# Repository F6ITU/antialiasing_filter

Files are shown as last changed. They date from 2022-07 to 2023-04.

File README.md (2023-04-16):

Cerberus, a triple path antialiasing filter for RF Software defined radio

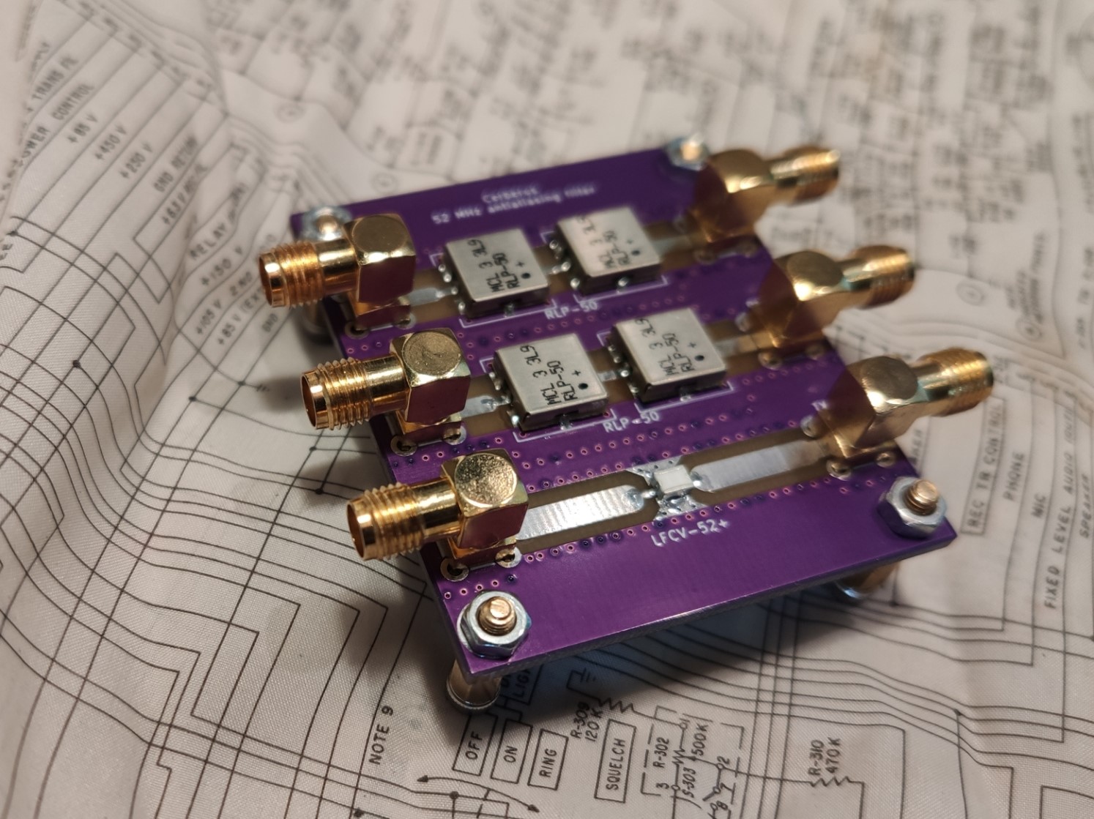
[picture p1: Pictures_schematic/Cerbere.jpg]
Cerberus, the 2 RX, 1 TX 52 MHz low path antialiasing filter


Cerberus is a simple series of three 52 MHz low pass filters designed to eliminate the second Nyquist zone of any "bare foot" 
120 MSPS baseband software defined HF transceiver. One filter is used in the Transmission path, two distinct filters could be used for 
two different RX path.

A single LTCC filter is dedicated to the TX output able to withstand up to 8W CW. It's rejection level is around 50 dB in the stopband area.
This filter should be  completed with a post-amplifier low pass filter. 

Two RX path (for 2 separated ADCs) are based on a pair of cascaded RLP-50+ low pass filters, thus offering a rejection of 50 dB each

Each of these path could be used with or without an RF preselector (bandpass filter or low pass filter) 

This antialiasing frontend should be inserted just after the baseband board (Red Pitaya 14 or 16 bits, IQsdr etc)and before 
the SDR frontend (in other words, a simple bandpass filter, a more complex "Alexiares like" preselector, or a combination of 
Alexiares or entry level filters and a set of high power frontend (Zolotaref lpf, Aries ATU, Munin amplifier etc

As usual, this board is under the CERN Open Hardware licence

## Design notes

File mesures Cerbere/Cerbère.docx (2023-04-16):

Cerbère (Κέρϐερος) est le chien tricéphale, gardien des enfers. Ce gardien-là préserve le SDR des démons provenant des secondes, troisièmes et quatrièmes zones de nyquist. C’est un triple filtre passe-bas destiné à tous les transceivers bande de base couvrant de 0,1 à 60 MHz et qui ne possèdent pas déjà ce genre de protection. C’est notamment le cas des cartes Red Pitaya 14 et 16 bits.

Cerbère fait précéder chacune des deux entrées réception (ADC) d’un double filtre Mini Circuits coupant à partir de 50 MHz. Cette cascade garanti une élimination de plus de 70 dB tout signal émis notamment dans la bande 88/108 MHz de la bande broadcast FM ou des émissions de la bande aviation située au-delà de 110 MHz.

La troisième section utilise un filtre LTCC également passe-bas, qui atténue de 50 dB tout produit harmonique au dessus de 52 MHz. Ce composant à peine plus gros qu’un condensateur MLCC 1210 peut encaisser 5W sans problème, et ainsi filtrer le signal de sortie d’un DAC associé à un pré-driver d’émission.

Les captures d’écran suivantes montrent successivement, pour une plage de fréquence couvrant de 1 à 120 MHz, le comportement des filtres réception en impédance (fig « Réception Smith »), en atténuation et en vswr (fig. « Réception Amplitude ») et enfin la courbe d’amplitude « gain/vswr » du filtre d’émission (fig. « Emission »)

Ressources

Le schéma, le dessin du PCB au format KiCad, les différentes feuilles de caractéristiques des deux composants principaux sont disponibles sur le dépôt github

https://github.com/F6ITU/antialiasing_filter

BOM

Bien que peu utile, (trois références de composants seulement) la BOM interactive peut être téléchargée depuis le lien

https://github.com/F6ITU/antialiasing_filter/blob/main/Documentation/ibom.html

Réalisation

Le montage du boitier GP731 (filtre réception RLP-50+) demande un peu d’attention.

- Badigeonnez l’empreinte du circuit imprimé avec une légère couche de flux
- Positionnez le filtre dans l’alignement du microstrip. Attention, le signal entre et sort des broches 2 et 6, les broches 1, 3, 4, 5, 7 et 8 étant reliées à la masse.
- Déposez un point de brasure sur l’un des contacts de masse 4 ou 8 (contacts latéraux) en veillant à l’alignement général. Il est possible d’utiliser les « via » du pcb comme repères de positionnement (Fg 1)
- Vérifiez l’alignement des contacts 2 et 6, retouchez éventuellement l’orientation du composant en chauffant le point de brasure réalisé précédemment.
- Ancrez le composant en déposant un point de soudure sur le contact de masse diamétralement opposé
- Achevez en soudant les 6 autres points de brasure, en prenant garde de ne pas créer de « pont » entre le microstrip « signal » et la masse.

Répétez l’opération pour les trois autres filtres RLP-50+

Le montage du filtre émission LFCV-52+ est légèrement différent.

- Badigeonnez l’empreinte du circuit imprimé avec une légère couche de flux
- Positionnez le filtre dans l’alignement du microstrip.
- Déposez un point de brasure sur l’un des contacts « Signal » (et surtout pas les contacts de masse latéraux).
- Vérifiez l’alignement du contact signal opposé, corrigez éventuellement la coaxialité du composant avec le microstrip en chauffant le point de brasure réalisé précédemment.
- Ancrez le composant en déposant un point de soudure sur le contact « signal » diamétralement opposé
- Achevez en soudant les 2 autres points de brasure sur les faces latérale (GND).
- Installez et soudez les 6 connecteurs SMA femelle
- Reliez Cerbère aux ports 1 à 3 de la carte Red Pitaya

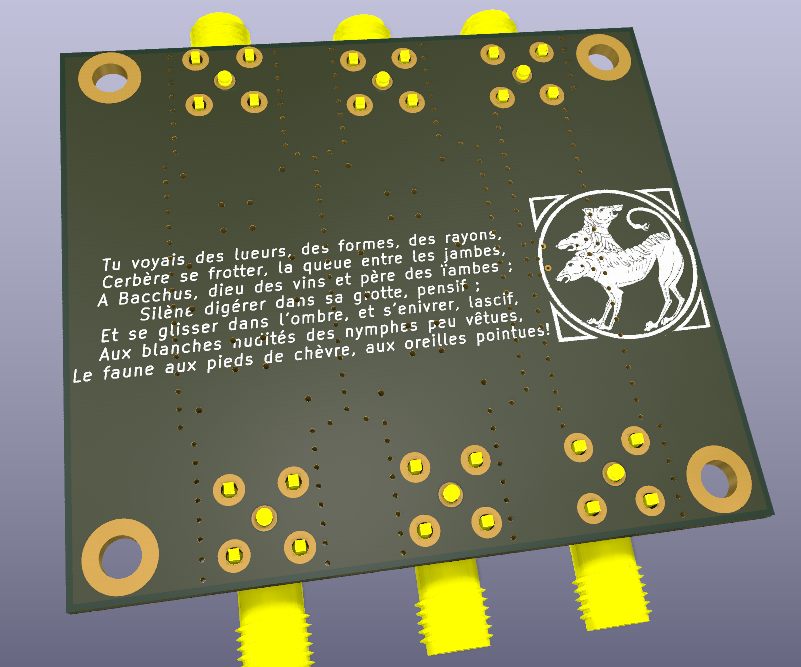
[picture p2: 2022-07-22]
Pictures_schematic/Cerberus_down.png

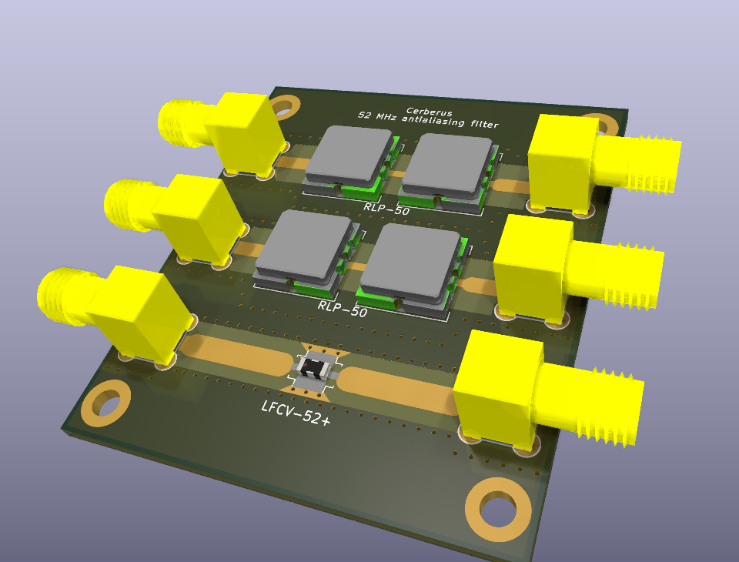
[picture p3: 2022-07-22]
Pictures_schematic/Cerberus_up.png

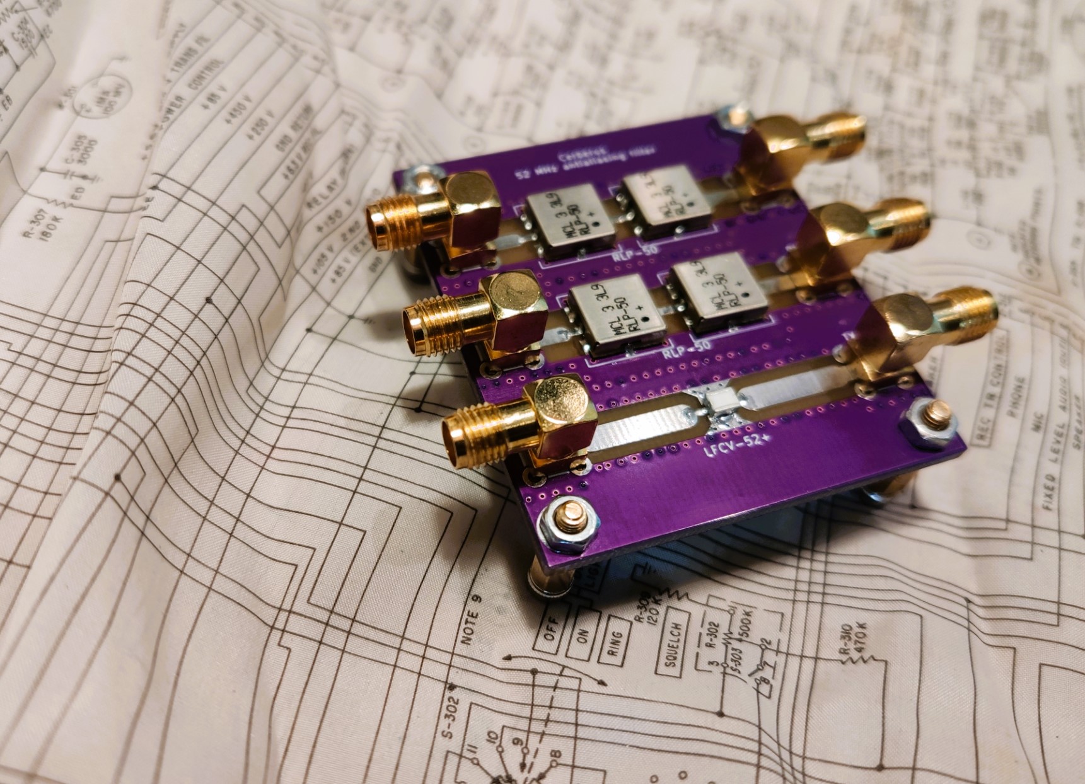
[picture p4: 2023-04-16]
cerbère final.jpg

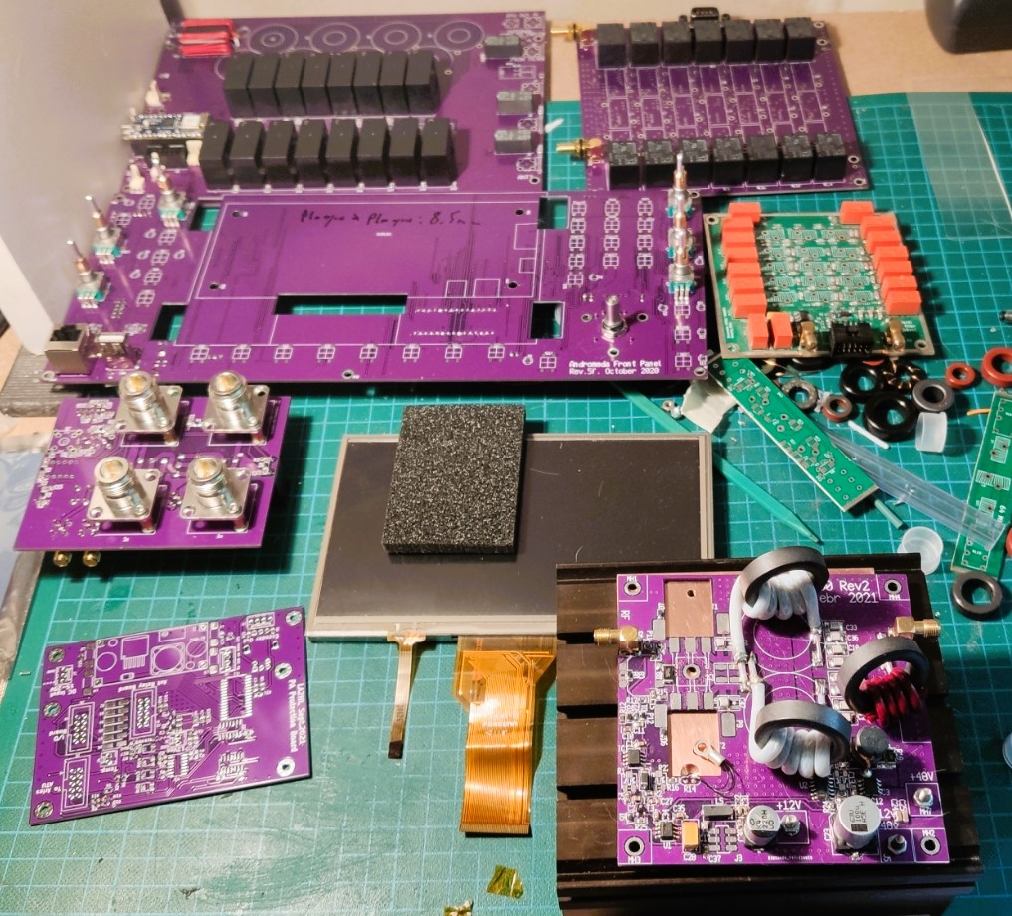
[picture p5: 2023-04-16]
ampli.jpg

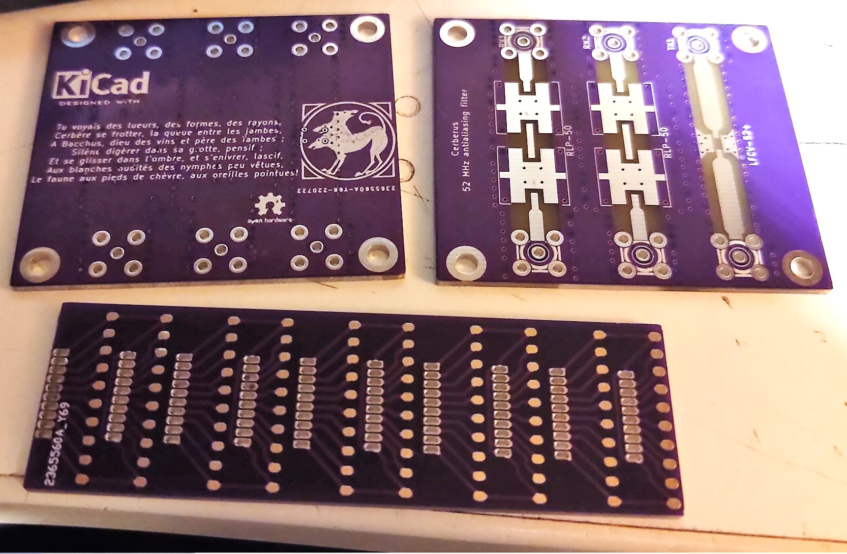
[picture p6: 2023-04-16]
cerbère.jpg

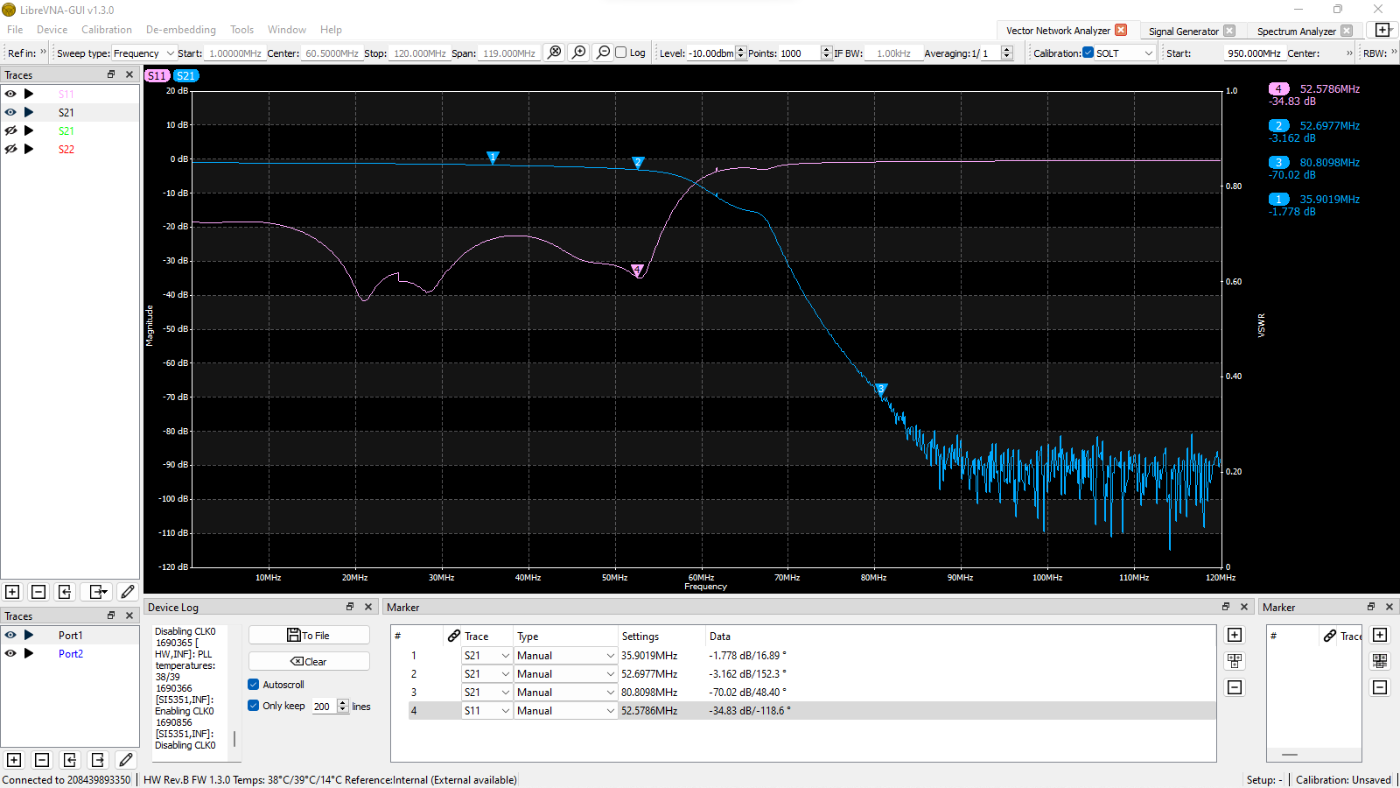
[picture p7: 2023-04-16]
mesures Cerbere/wiki/Cerbere_RX1_S21.png

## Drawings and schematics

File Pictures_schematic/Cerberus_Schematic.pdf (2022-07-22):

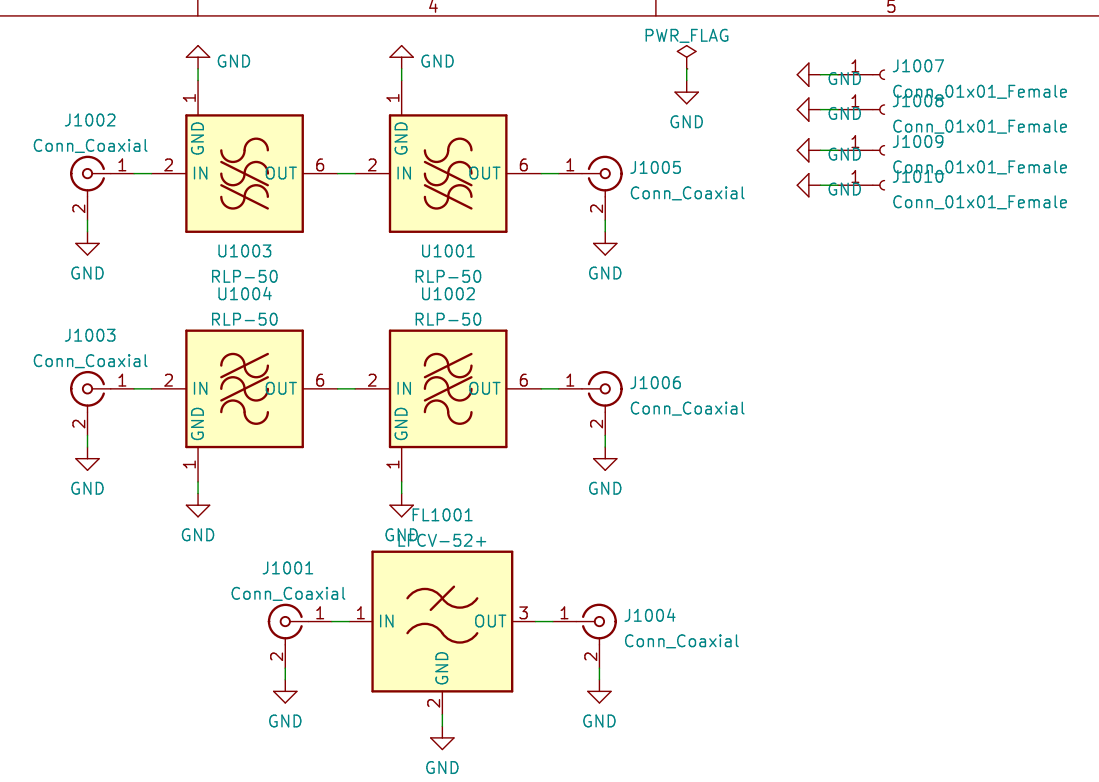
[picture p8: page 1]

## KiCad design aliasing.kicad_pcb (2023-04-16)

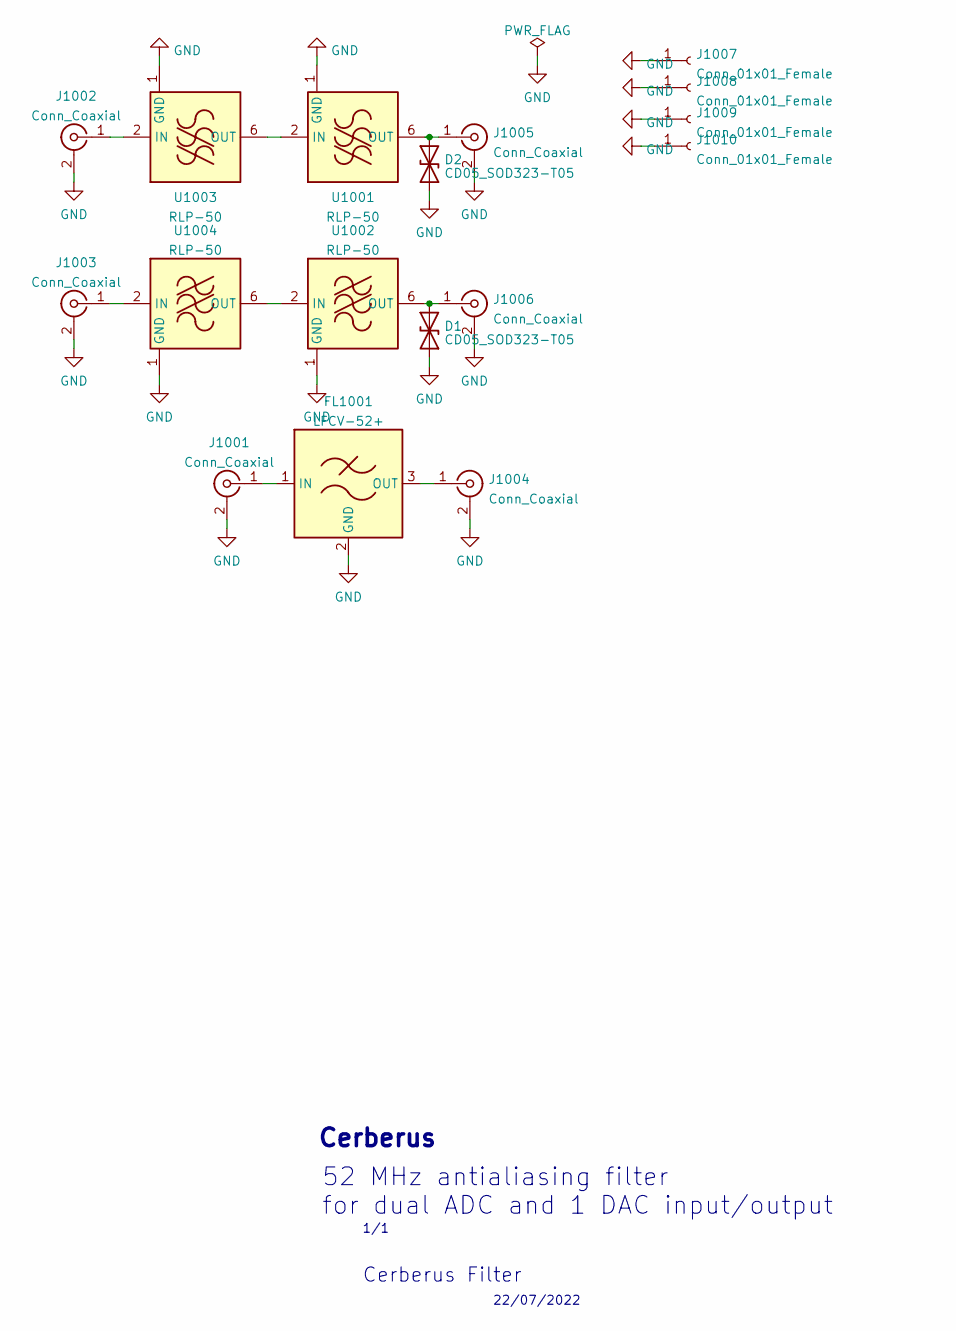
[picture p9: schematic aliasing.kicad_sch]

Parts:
D1, D2: CD05_SOD323-T05; D_SOD-323
FL1001: LFCV-52+; Filter_Mini-Circuits_FV1206
J1001, J1002, J1003, J1004, J1005, J1006: Conn_Coaxial; SMA_PINS
J1007, J1008, J1009, J1010: Conn_01x01_Female; MountingHole_3.2mm_M3_ISO7380_Pad
U1001, U1002, U1003, U1004: RLP-50; Mini-Circuits_GP1212_LandPatternPL-176

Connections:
GND: D1.1 (A1), D2.1 (A1), FL1001.2 (GND), FL1001.4 (GND), J1001.2 (Ext), J1002.2 (Ext), J1003.2 (Ext), J1004.2 (Ext), J1005.2 (Ext), J1006.2 (Ext), J1007.1, J1008.1, J1009.1, J1010.1, U1001.1 (GND), U1001.3 (GND), U1001.4 (GND), U1001.5 (GND), U1001.7 (GND), U1001.8 (GND), U1002.1 (GND), U1002.3 (GND), U1002.4 (GND), U1002.5 (GND), U1002.7 (GND), U1002.8 (GND), U1003.1 (GND), U1003.3 (GND), U1003.4 (GND), U1003.5 (GND), U1003.7 (GND), U1003.8 (GND), U1004.1 (GND), U1004.3 (GND), U1004.4 (GND), U1004.5 (GND), U1004.7 (GND), U1004.8 (GND)
unnamed: D1.2 (A2), J1006.1 (In), U1002.6 (OUT)
unnamed: D2.2 (A2), J1005.1 (In), U1001.6 (OUT)
unnamed: FL1001.1 (IN), J1001.1 (In)
unnamed: FL1001.3 (OUT), J1004.1 (In)
unnamed: J1002.1 (In), U1003.2 (IN)
unnamed: J1003.1 (In), U1004.2 (IN)
unnamed: U1001.2 (IN), U1003.6 (OUT)
unnamed: U1002.2 (IN), U1004.6 (OUT)

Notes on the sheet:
22/07/2022
Cerberus
Cerberus Filter
52 MHz antialiasing filter for dual ADC and 1 DAC input/output
1/1

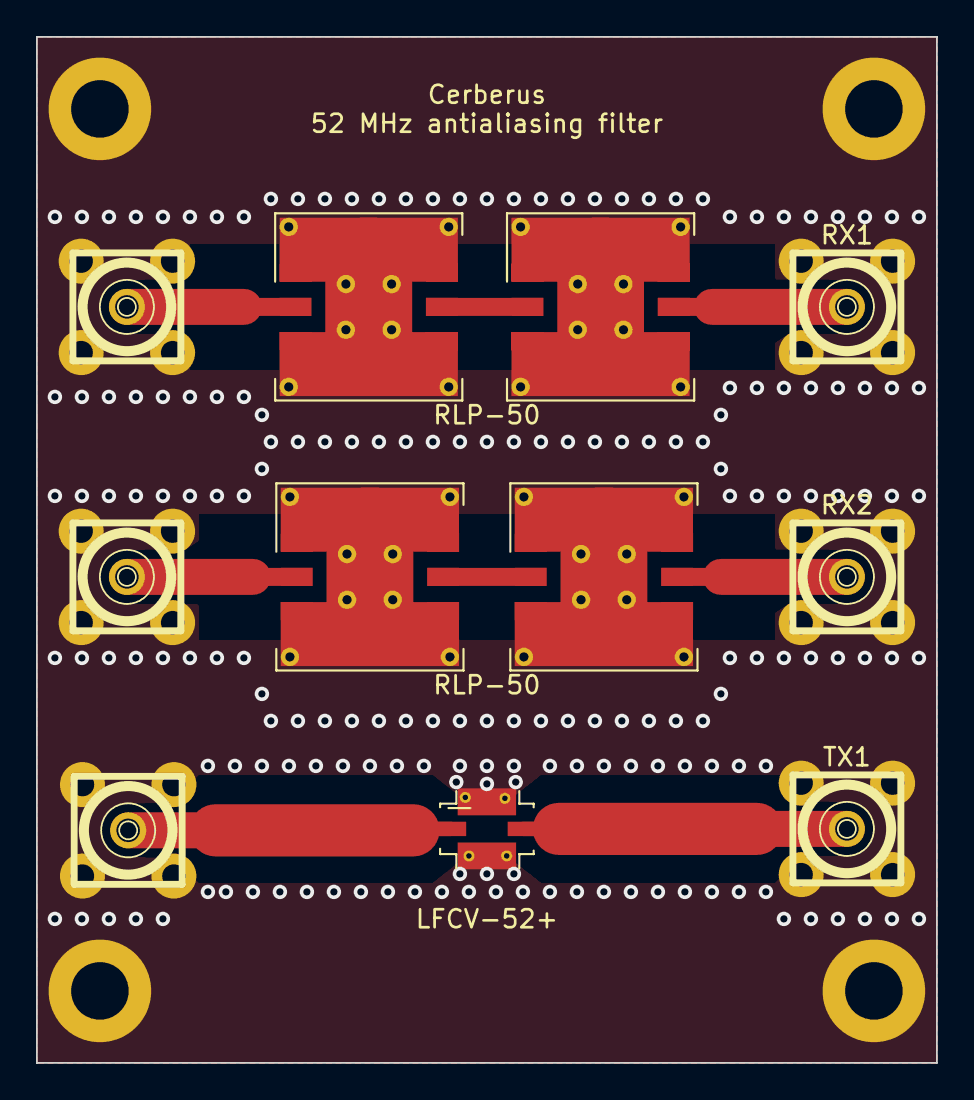
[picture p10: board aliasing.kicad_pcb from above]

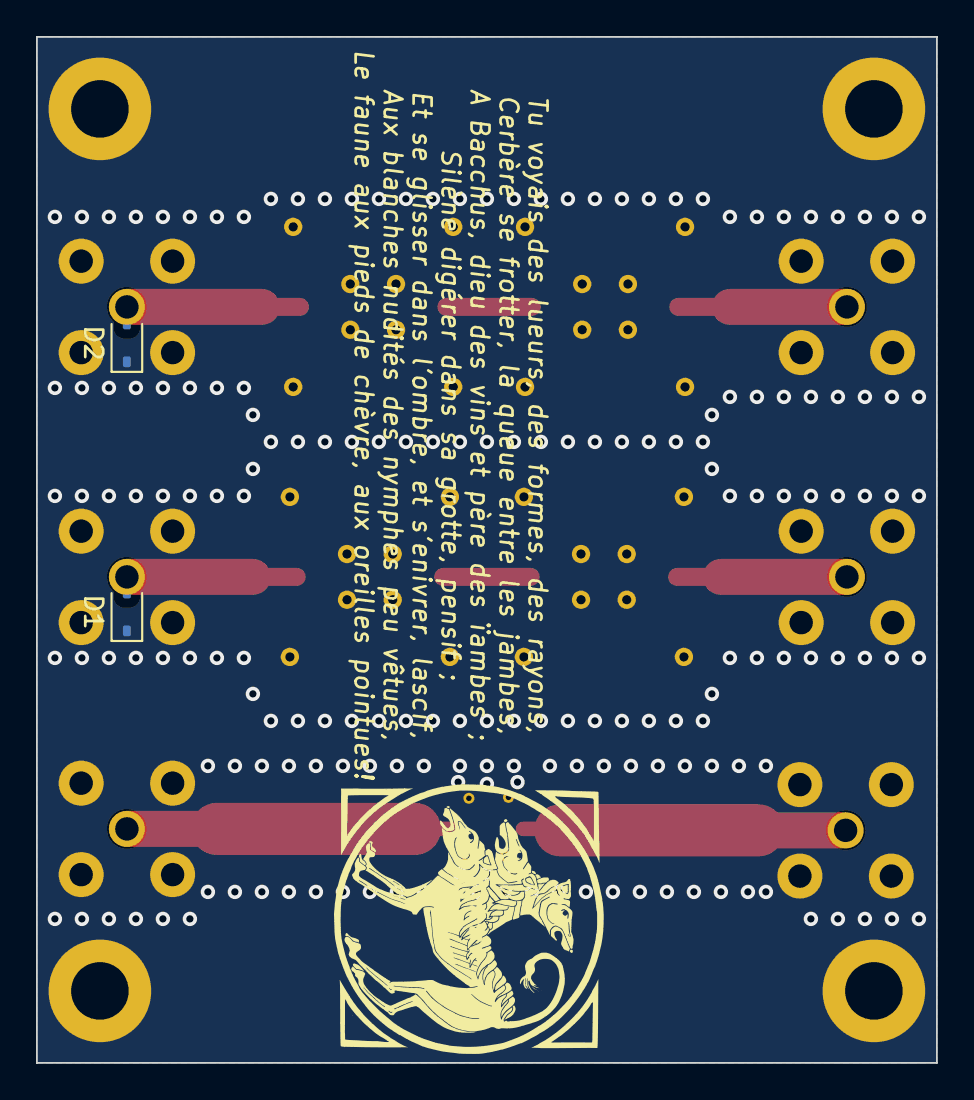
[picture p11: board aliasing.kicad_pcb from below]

Board: 2 copper layers, 50.0 x 57.0 mm, 17 parts (2 on the bottom side), 9 nets.

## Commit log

2022-07-22 first commit, pcb clean
    [aliasing-B_Cu.gbr, aliasing-B_Mask.gbr, aliasing-B_Paste.gbr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]
2022-07-22 Silkmask cleaning, new set of Gerber files
    [aliasing-B_Cu.gbl, aliasing-B_Mask.gbs, aliasing-B_Paste.gbp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]
2022-07-23 excentred mounting hole corrected
    [aliasing.kicad_pcb]
2022-07-23 excentred mounting hole corrected, new gerber
    [aliasing-B_Cu.gbl, aliasing-B_Mask.gbs, aliasing-B_Paste.gbp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]
2022-08-08 new ibom, new picture, new readme
    [aliasing.kicad_pcb]
2022-08-15 minor changes in pcb and Readme
    [aliasing.kicad_pcb]
2023-04-16 TLV diodes added, new gerber, minor modif.
    [aliasing-B_Cu.gbl, aliasing-B_Mask.gbs, aliasing-B_Paste.gbp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]
